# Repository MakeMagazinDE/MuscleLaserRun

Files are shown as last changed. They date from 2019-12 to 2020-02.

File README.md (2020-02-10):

GitHub Logo

Maker Media GmbH und c't, Heise Zeitschriften Verlag

***

# MuscleLaserRun

Spannen Sie mal Ihren linken Unterarm an. Hat es geklappt? Ein Gedanke reicht, um unsere Körper Erstaunliches leisten zu lassen – zum Beispiel eine Muskelkontraktion. Diese Muskelkontraktion wird durch elektrische Impulse ausgelöst, die man Biosignale nennt. Mit dem Bau des Laserparcours Muscle Laser Run haben wir Biosignale spielerisch erkundet.

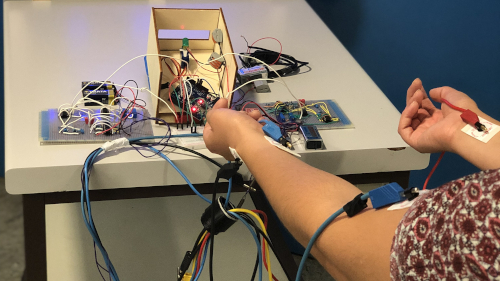
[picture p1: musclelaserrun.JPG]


Den vollständigen Artikel mit der Bauanleitung unter dem Titel "MuscleLaserRun" gibt es ab 11. Dezember 2019 in der **[Make-Ausgabe 6/19](https://www.heise.de/select/make/2019/6/)** zu lesen. Hier bei GitHub gibt es hingegen die Materialliste, die  Lasercutter-Schnittvorlagen und den Arduino-Code zum Download. 

Für Fragen rund um den Solar Racer sowie alle anderen Projekte aus der Make-Ausgabe 6/19 hat die Make-Redaktion ein eigenes [Online-Forum](https://www.heise.de/forum/Make/Heft-Projekte/Artikelforum-Heft-6-2019/forum-437905/) eingerichtet.

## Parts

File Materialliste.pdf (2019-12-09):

Materialliste
Artikel | Anzahl
Rasterplatte/Platine | 2
isolierte Drähte | Rolle
Jumper Kabel | Big Pack
3V Batterie | 5
Klebeelektroden | min. 6
Kontaktgel | 1
Widerstand 8,2 MΩ | 2 (R0_1 und R0_2)
Widerstand 1,0 kΩ | 2 (R1_1 und R1_2)
Widerstand 2,0 kΩ | 4 (R2_1, R2_2, R3_1 und R3_2)
Widerstand 1,0 MΩ | 2 (RN1_1 und RN1_2)
Widerstand 470 kΩ | 1 (RN_2)
Widerstand 30 kΩ | 1 (RN_2)
Widerstand 27 kΩ | 2 (RN3_1 und RN3_2)
Kondensator 220 nF | 2 (C1_1 und C1_2)
Kondensator 4,7 nF | 1 (C2_1)
Kondensator 1,5 nF | 5 (C2_2, C3_1, C3_2, C4_1 und C4_2)
Kondensator 100 pF | 1 (C2_3)
Kondensator 150 pF | 2 (C3_3, C4_3)
Operationsverstärker LMC6484IN | 2
Potentiometer 500 Ω | 1
Lasermodul Punkt (Laserdiode 1 mW) | 1
Mirco Servo 9g SG90 | 1
Arduino UNO 65139 ATMega 328 | 2
Steckplatine | 1
Plastikwinkel | 8
Holzplatten
Taster | 2
Verbindungsklemmen | 5
Batterieklipp | 6
MOS Ansteuerungsmodul (VMA 411) | 1
1,5 V (AA)-Batterien Alkali-Mangan | 10
Batteriehalter 10x Mignon (AA) Druckknopfanschluss | 1
Schottky-Diode Gleichrichter (MBR 5200) | 1
Metallstangen | 6
Getriebemotor 12 V (1:200) | 1
Holzlatte
LED-Streifen-Komplettset mit Stecker (500 cm) | 1
Papierbahn (Breite 48 cm) | 1
Krokodilklemmen | 2
Gaffer Tape | 1 Rolle
Bananenstecker | 8
Lüsterklemmen | 2

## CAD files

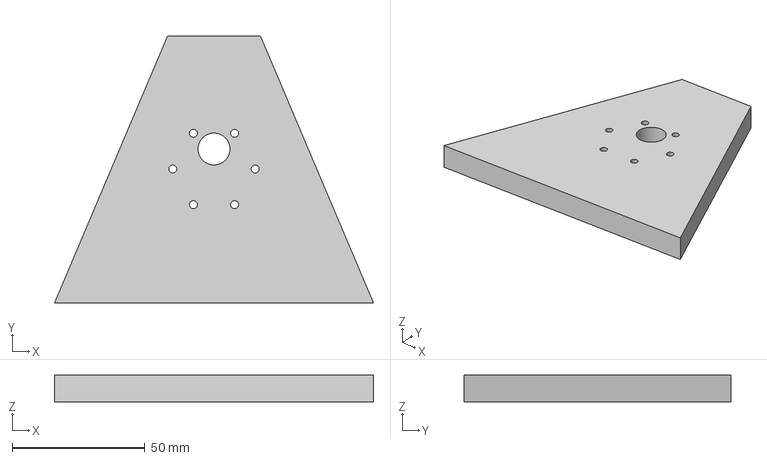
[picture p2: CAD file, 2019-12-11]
Motorfixierung.step
120.0 x 100.3 x 10.0 mm

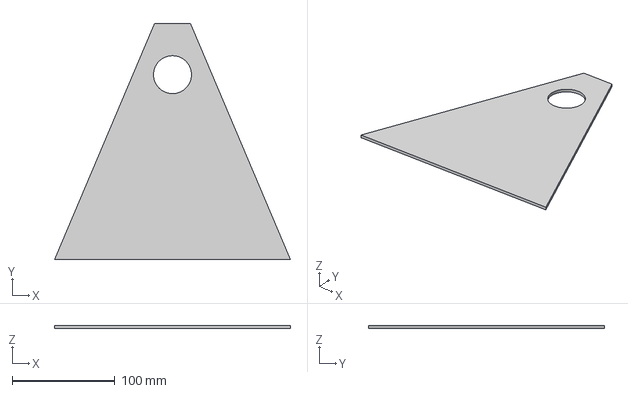
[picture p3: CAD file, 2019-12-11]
Verkleidung_Seitengestell.step
230.0 x 230.2 x 3.00 mm

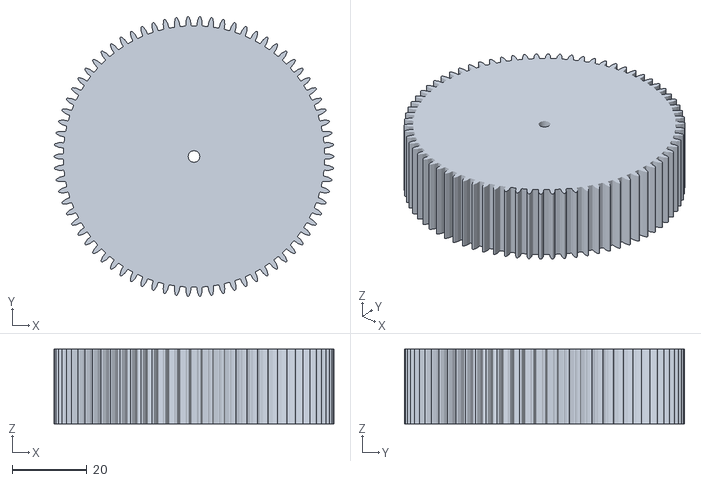
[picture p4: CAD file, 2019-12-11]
Zahnrad_Metallstange.STL
75.0 x 74.9 x 20.0

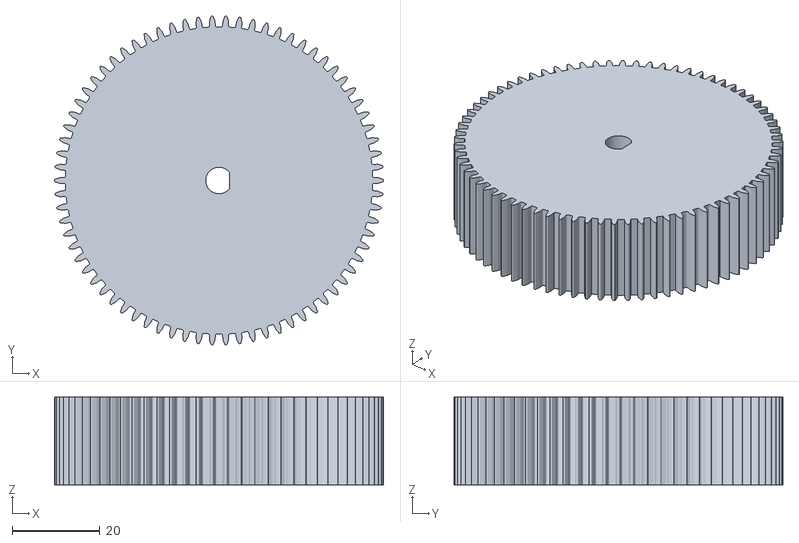
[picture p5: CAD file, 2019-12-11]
Zahnrad_Motor.STL
75.0 x 74.9 x 20.0

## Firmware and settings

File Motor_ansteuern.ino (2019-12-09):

#include "HCMotor.h" //Bibliothek zum steuern eines Motors
#define FAN 6 //IRF520 MOS Driver am digitalen PIN 6

HCMotor fan; 
void setup(){
  Serial.begin(9600);
  fan.Init();
  fan.attach(0, DCMOTOR, FAN);
  fan.DutyCycle(0, 100); //minimale 0 und maximale Geschwindigkeit 100
}
  
void loop(){
  //Wenn auf dem seriellen Eingang ein Wert anliegt dann....
  while(Serial.available() > 0){
  //Den Wert vom seriellen Eingang lesen und in einen Ganzzahligen Wert umwandeln.
  //Wenn nun ein Text eingegeben wird tritt hier ein Fehler auf. 
  //Der Code müsste also etwas robuster Programmiert werden.
  int value = Serial.readString().toInt();
  //Mappen der Werte, d.h. es wird der Wertebereich 0 bis 1024 auf 0 bis 100 transformiert.
  int fanSpeed = map(value, 0, 1024, 0, 100);
  fan.OnTime(0, fanSpeed); //Setzen der Geschwindigkeit am ersten Motor.
  }
  
}

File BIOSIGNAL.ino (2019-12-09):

#include <Servo.h>

Servo myservo;
int LINKS = A3;
int L = 0;
int RECHTS = A2;
int R = 0;
int pos = 90;  //Position Laserservo

int thresholdL = 5; 
int thresholdR = 150;

void setup() {
Serial.begin(9600);
myservo.attach(9);}

void loop() {
L = analogRead(LINKS);
R = analogRead(RECHTS);

//Serial.println(L);
//Serial.println(R);

if ( L >= thresholdL && L>= R && pos <= 130){ // Linker Arm angespannt, rechter entspannt
  myservo.write(pos);
  delay(20);
  pos += 1;}
else if ( R >= thresholdR && R >= L && pos >= 70){
  myservo.write(pos);
  delay(20);
  pos -= 1;} // niedriger Wert bedeutet Laser zeigt nach rechts
}

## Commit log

2019-12-09 Added Arduino Code for the buttons
2019-12-09 added Arduino code for biosignals
2019-12-09 added Arduino code for motor control
2019-12-09 Added material list
2019-12-09 added EAGLE file
    [EAGLE_Schaltplan.sch]
2019-12-11 Added 3D-printing files
    [Zahnrad_Metallstange.STL, Zahnrad_Motor.STL]
2019-12-11 Added lasercutter files
    [Motorfixierung.step, Verkleidung_Seitengestell.step]
2019-12-11 Added box svg for lasercutting
2019-12-11 Added Gerber files
